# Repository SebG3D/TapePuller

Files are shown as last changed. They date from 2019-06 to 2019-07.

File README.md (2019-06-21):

# TapePuller
tape puller/remover for 0816 automatic feeder which stays within the width of the feeder itself.
Now you will be able to remove on single feeder from your feederbank.

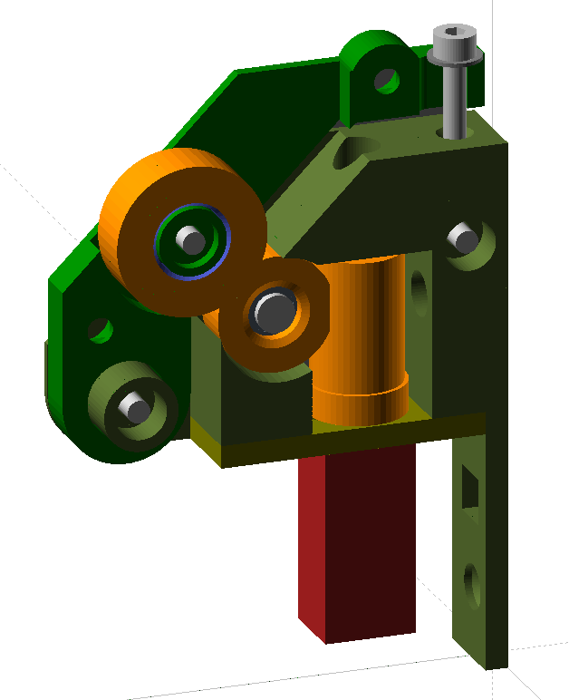
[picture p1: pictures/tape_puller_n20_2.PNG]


Work in progress.
See [wiki](https://github.com/SebG3D/TapePuller/wiki) for details

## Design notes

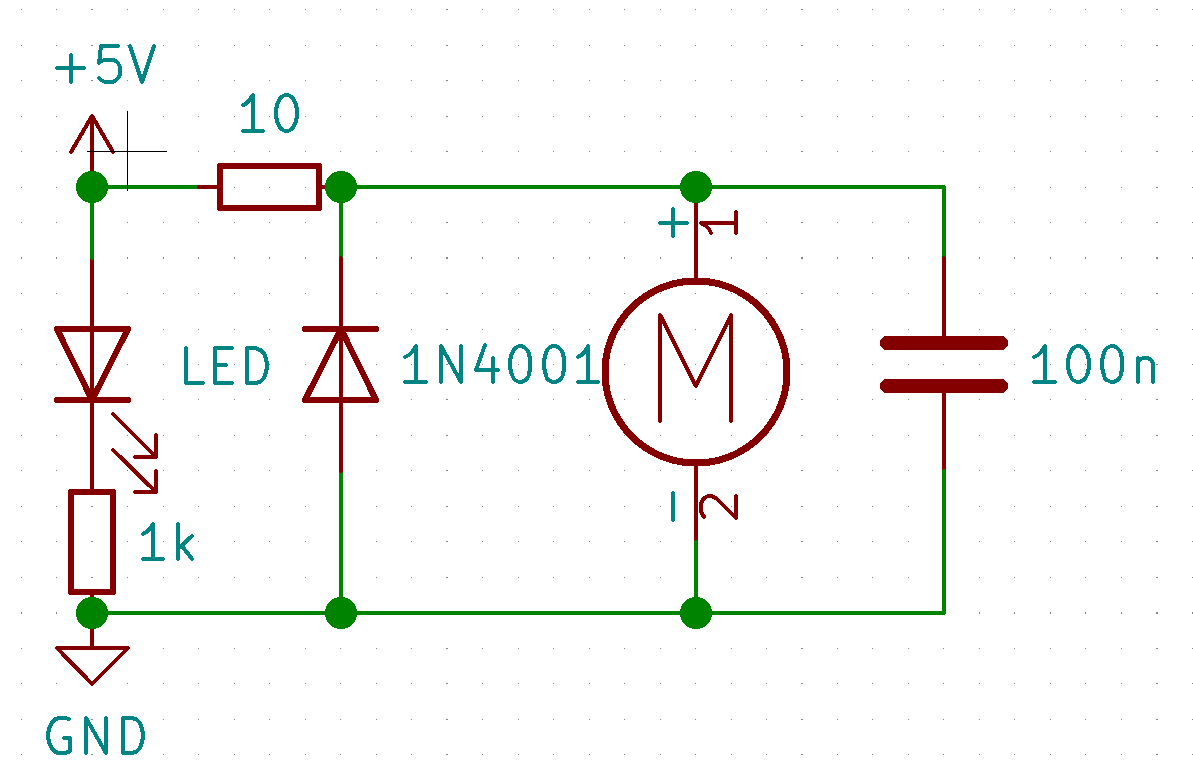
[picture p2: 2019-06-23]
docs/servo/servo_schematic/servo_Schematic.PNG

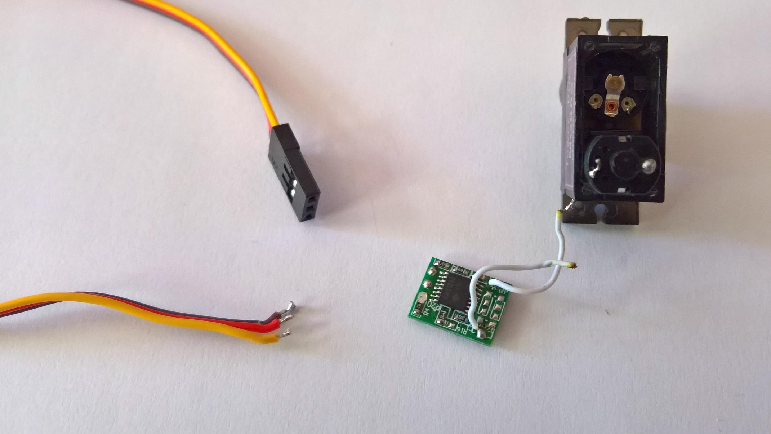
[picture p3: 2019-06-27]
docs/servo/servo_mod/servo_mod_3.jpg

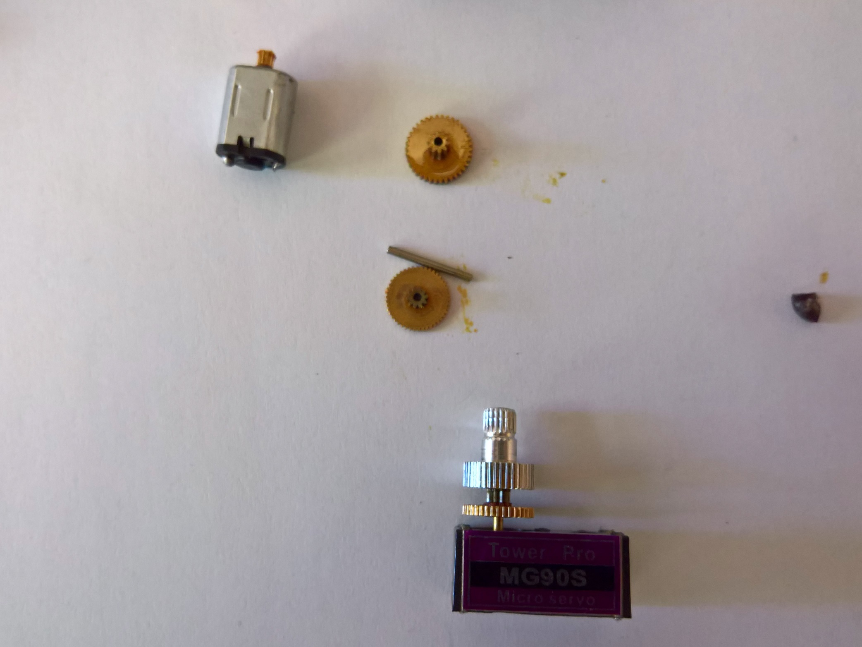
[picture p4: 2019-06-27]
docs/servo/servo_mod/servo_mod_9.jpg

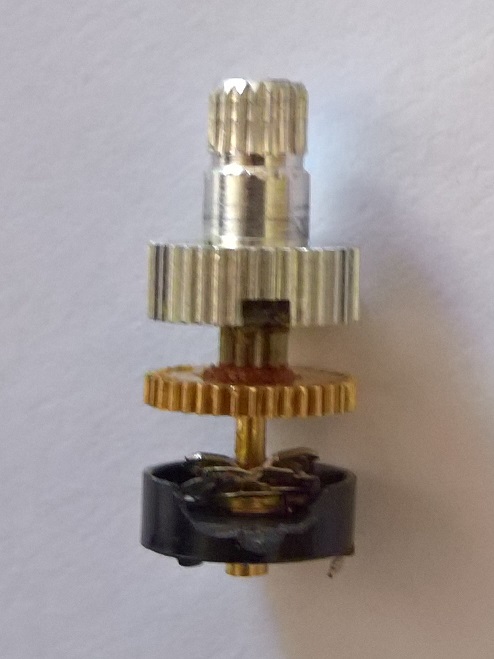
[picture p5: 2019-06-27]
docs/servo/servo_mod/servo_mod_8.jpg

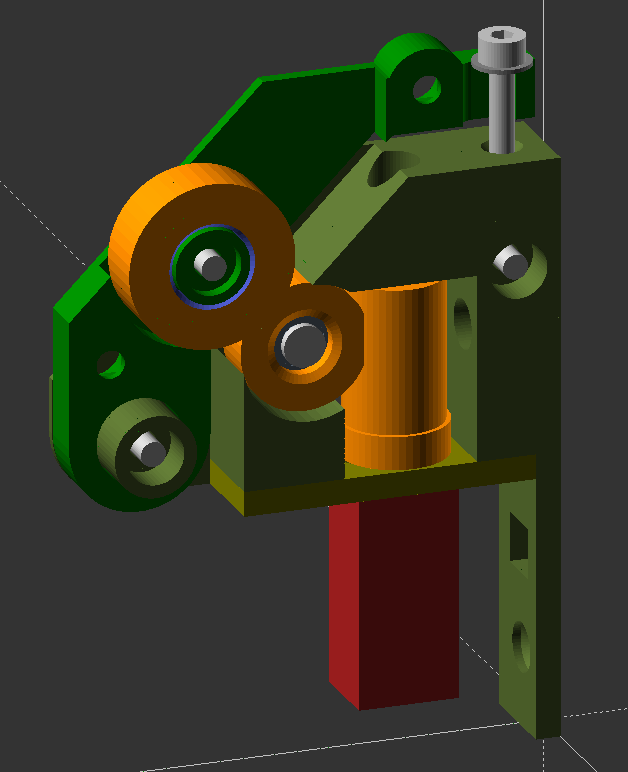
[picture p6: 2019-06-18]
pictures/tape_puller_n20_wo_lid.PNG

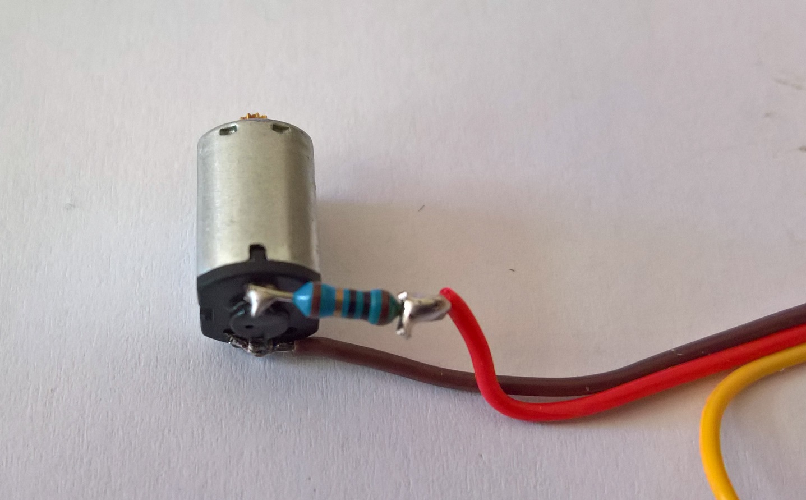
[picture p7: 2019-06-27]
docs/servo/servo_mod/servo_mod_13.jpg

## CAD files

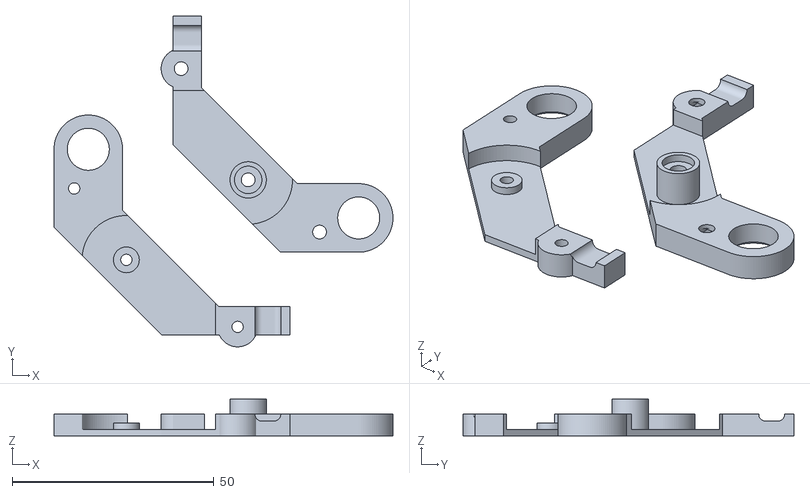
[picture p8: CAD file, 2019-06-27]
STLs/lever_mg90_post.stl
84.0 x 82.0 x 9.12

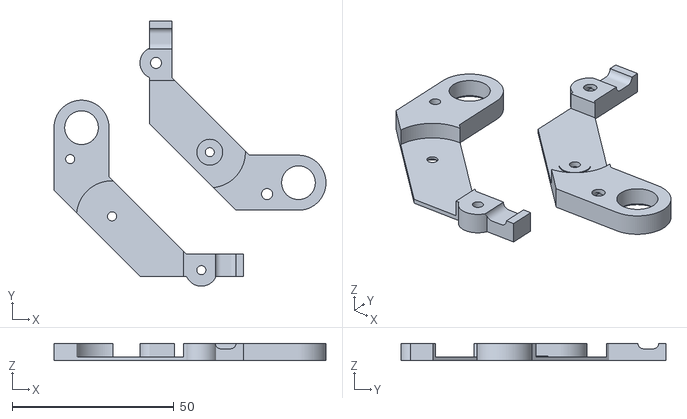
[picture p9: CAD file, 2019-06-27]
STLs/lever_mg90_pin.stl
84.0 x 82.0 x 5.38

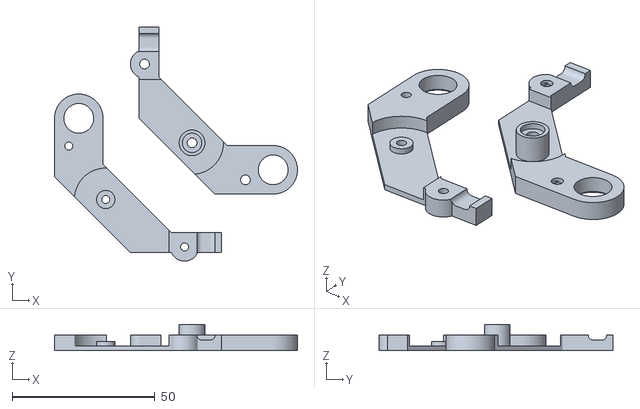
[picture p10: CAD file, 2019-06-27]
STLs/lever_sg90_post.stl
85.0 x 82.0 x 9.12

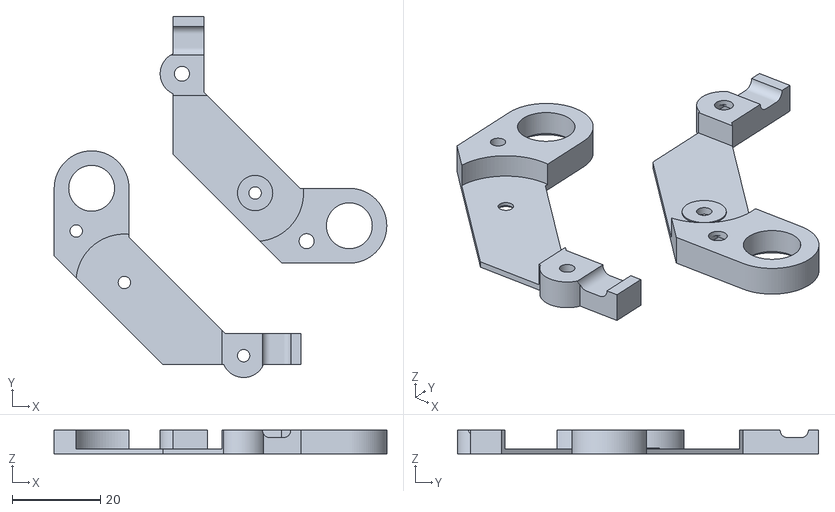
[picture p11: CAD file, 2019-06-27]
STLs/lever_n20_pin.stl
75.5 x 82.0 x 5.38

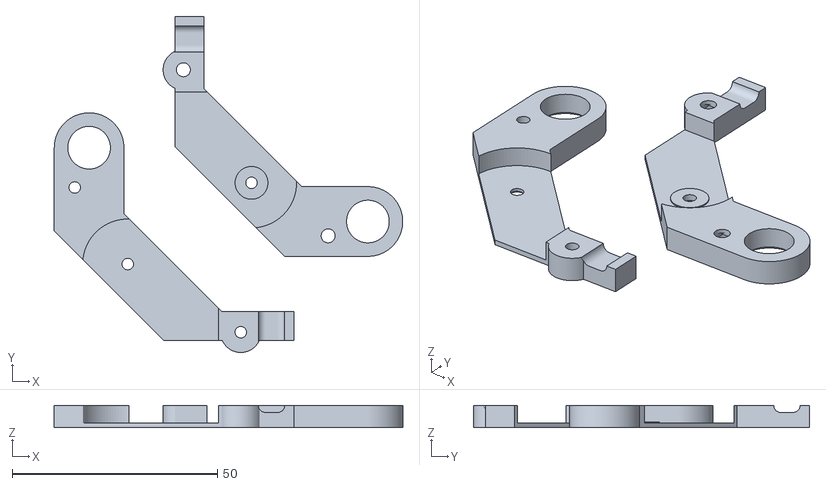
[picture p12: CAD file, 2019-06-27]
STLs/lever_sg90_pin.stl
85.0 x 82.0 x 5.38

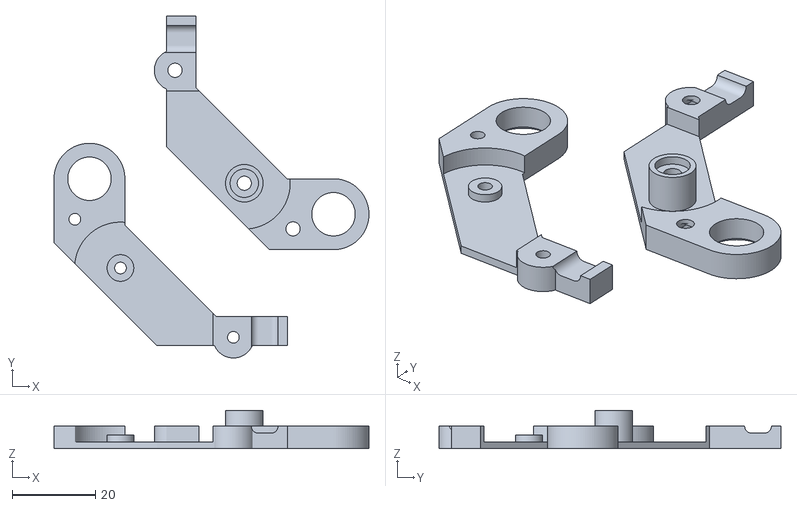
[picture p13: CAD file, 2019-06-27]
STLs/lever_n20_post.stl
75.5 x 82.0 x 9.12

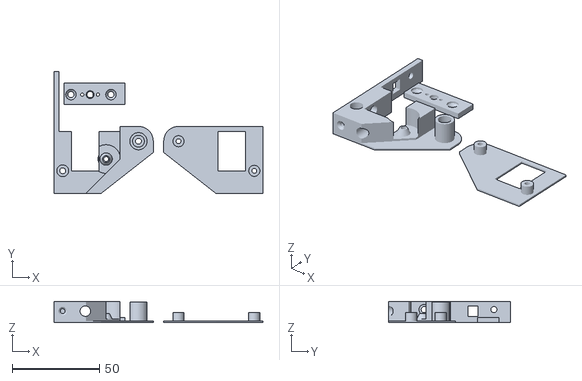
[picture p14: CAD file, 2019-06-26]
STLs/case_N20_ballbearing.stl
120.0 x 70.0 x 12.2

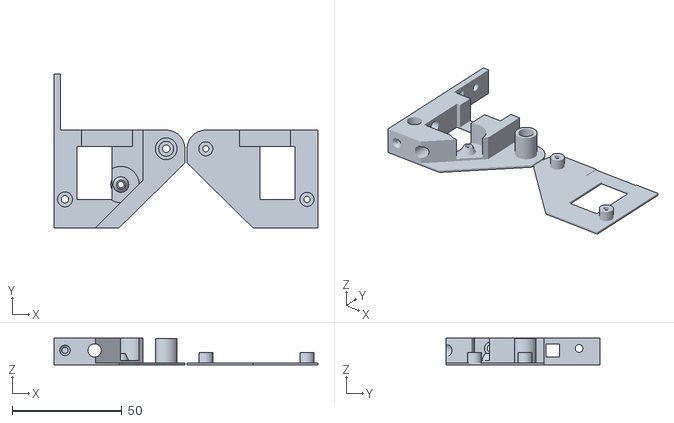
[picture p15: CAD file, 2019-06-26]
STLs/case_mg90_ballbearing.stl
120.0 x 70.0 x 12.2

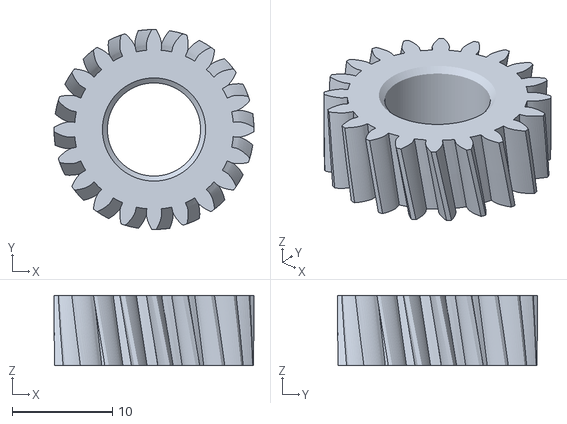
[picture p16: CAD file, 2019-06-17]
STLs/pinnion_2_post.stl
20.0 x 20.0 x 7.00

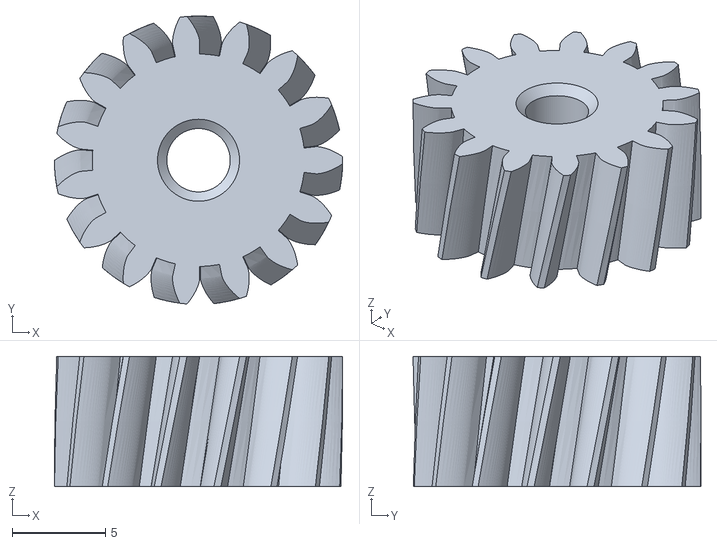
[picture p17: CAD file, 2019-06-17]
STLs/pinnion_1_pin.stl
15.5 x 15.5 x 7.00

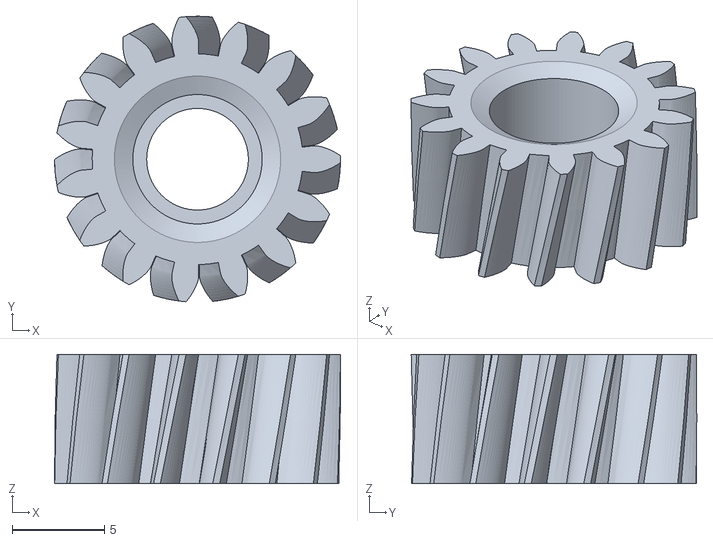
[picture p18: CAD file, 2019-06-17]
STLs/pinnion_1_ballbearing.stl
15.5 x 15.5 x 7.00

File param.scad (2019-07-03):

//-----------------------------------------------------------------------
//                  FEEDER PARAM
//-----------------------------------------------------------------------
//Feeder_Width = 13.5; //[13.5:8mm tape, 16:12mm tape, 20:16mm tape, 28:24mm tape]
feeder_width_list = [13.5,16,20,28];			//list of feeder width for different SMD tape width
Feeder_Width = feeder_width_list[SMD_Tape_Width];
feeder_mount_y_list = [7.55,9.55,11.55,15.55];		//list of y positions for feeder width
feeder_mount_y = feeder_mount_y_list[SMD_Tape_Width];


//-----------------------------------------------------------------------
//                  3D PRINTING PARAM
//-----------------------------------------------------------------------
M3_drill_hole_d = 3D_Printing_M3_tap/1000;  //diameter to directly screw M3 screws in
M3_loose_hole_d = 3D_Printing_M3_through/1000;  //diameter for thouhole
head_912_loose_d = 3D_Printing_M3_head/1000;  //head of a 912 screw helps for worm gear alighnment

//param for gear_mount = 1
gears_pinion_mount_screw = 3D_Printing_Mount_head/1000; //used for geartype==1 gear runs on screw head M3
//param for gear_mount = 2
pin_d_loose = 3D_Printing_Pin_loose/1000;              //hole diameter for loose pin
pin_d_fixed = 3D_Printing_Pin_pressfit/1000;             //hole diameter for press fit
gears_pinion_mount_shim = Shim_Thickness/1000;  //thickness of shim
//param for gear_mount = 3
gears_pinion_mount_683 = 3D_Printing_683_pressfit/1000;   //hole for bearing press fit
gears_pinion_mount_623 = 10.0;   //hole for bearing press fit
//param for gear_mount = 4
gears_pinion_mount_post_id = 9;     //needs to fit in od
gears_pinion_mount_post_od = 3D_Printing_Post_loose/1000;   //needs to fit id

//screw post param for case
//top has cylinder with scew in hole
//bottom has through hole and countersunk scew
case_post_top_od = M3_drill_hole_d + 8*3dp_ew;                   //top outer diameter
case_post_bot_id = head_912_loose_d+0.3;                 //bottom inner diameter needs to fit screw head
case_post_bot_od = case_post_bot_id+8*3dp_ew;  //bottom outer diameter
case_post_bot_id2 = case_post_top_od+0.4; //bottom inner diameter 2 needs to fit top outer diameter


pi = 3.14159;
//-----------------------------------------------------------------------
//                  GEARS PARAM
//-----------------------------------------------------------------------
//param gears, no need to change anything here
RPM_300 =  [20,10,0.9,15,20,2];
RPM_200 =  [20,17,1.0,14,20,3];
RPM_150 =  [20,22,1.0,13,20,4];
RPM_List = [RPM_300,RPM_200,RPM_150];
RPM_Values = RPM_List[N20_RPM];

gears_pressure_angle = RPM_Values[0];              //pressure angel for gears
gears_lead_angle = RPM_Values[1];                  //lead angle for gears
gears_module = RPM_Values[2];                     //module for gearset
gears_pinion1_teeth = RPM_Values[3];                //number of theeth for pinio gears
gears_pinion2_teeth = RPM_Values[4];                //number of theeth for pinio gears
gears_pinion_with = round_lh(Feeder_Width-6.5);                  //with of pinion gears
gears_worm_threads = RPM_Values[5];                 //number of threads on worm gear

//gears_pressure_angle = 20;              //pressure angel for gears
//gears_lead_angle = 10;                  //lead angle for gears
//gears_module = 0.9;                     //module for gearset
//gears_pinion1_teeth = 15;                //number of theeth for pinio gears
//gears_pinion2_teeth = 20;                //number of theeth for pinio gears
//gears_pinion_with = round_lh(Feeder_Width-6.5);                  //with of pinion gears
//gears_worm_threads = 2;                 //number of threads on worm gear
gears_worm_height = round_lh(22);                 //height of worm gear
gears_pinion_mount_683_through = 5.5;   //through hole diameter for 683
gears_pinion_mount_623_through = 8;   //through hole diameter for 623
//some calculated values
c = gears_module / 6;					// Kopfspiel
gears_worm_r = gears_module*gears_worm_threads/(2*sin(gears_lead_angle));		// Teilzylinder-Radius Schnecke
gears_pinion1_r = gears_module*gears_pinion1_teeth/2;									// Teilkegelradius Stirnrad
gears_pinion2_r = gears_module*gears_pinion2_teeth/2;
gears_pinion1_df = 2*gears_pinion1_r - 2 * (gears_module + c);//inner diameter/start of teeth
gears_pinion2_df = 2*gears_pinion2_r - 2 * (gears_module + c);//inner diameter/start of teeth
gears_worm_rf = gears_worm_r - gears_module - c;						// Fußzylinder-Radius
//gamma = -90*gears_pinion_with*sin(gears_lead_angle)/(pi*gears_pinion_r);			// Rotationswinkel Stirnrad
gears_tooth_dist = gears_module*pi/cos(gears_lead_angle);				// gears_tooth_dist im Transversalschnitt
gears_pinion1_ad = (gears_module <1)? gears_pinion1_r*2 + gears_module * 2.2 : gears_pinion1_r*2 + gears_module * 2;				// Kopfkreisdurchmesser nach DIN 58400 bzw. DIN 867
gears_pinion2_ad = (gears_module <1)? gears_pinion2_r*2 + gears_module * 2.2 : gears_pinion2_r*2 + gears_module * 2;
gears_worm_da = gears_worm_r*2.3;

//-----------------------------------------------------------------------
//                  CASE
//-----------------------------------------------------------------------
case_h = 70; //hight of tapepuller case
case_w = round_lh(Feeder_Width - 3dp_lh);
case_walls=3;                           //wall thickness for test assemblys
case_walls_z = 4*3dp_lh;		//wall thickness in Z
case_tape_channel = 2;                  //with of tape channel
case_offset_n20 = 20;			//offset form worm x to tape channel if n20 motor is used

//Feeder_Width = 13.5; //[13.5:8mm tape, 16:12mm tape, 20:16mm tape, 28:24mm tape]
//feeder_width_list = [13.5,16,20,28];			//list of feeder width for different SMD tape width
//Feeder_Width = feeder_width_list[SMD_Tape_Width];
//feeder_mount_y_list = [7.55,9.55,11.55,15.55];		//list of y positions for feeder width
//feeder_mount_y = feeder_mount_y_list[SMD_Tape_Width];

//pramam for positioning
gear1z = case_h-case_walls-gears_pinion1_r-6-4;
//calc gear2 z position with 45°
gear2z = gear1z + (gears_pinion1_r+gears_pinion2_r)/sqrt(2);
wormx = (Motor_Type == 2)? 18 : (servo_mount_l/2-servo_shaft_dist+case_walls+0.5+4);
//wormx = servo_mount_l/2-servo_shaft_dist+case_walls+0.5+4;
gear1x = wormx+gears_worm_r+gears_pinion1_r;
gear2x = gear1x+sqrt(pow(gears_pinion1_r+gears_pinion2_r,2)-pow(gear1z-gear2z ,2));
//added -3,5 for 912 screwhead
wormz = case_h-gears_worm_height-case_walls-0.5-3.5-6;

// param for case lever
case_lever_w = case_w-2*case_walls_z-2*3dp_lh;   //with of lever
case_lever_t1 = 7;                                        //thickness above case
case_lever_t2 = 17;                                       //thickness behind case
rotate_x = (Motor_Type == 2)? (wormx + case_offset_n20 + case_tape_channel+case_lever_t2/2) : (wormx + servo_shaft_dist + servo_mount_l/2 + case_tape_channel+case_lever_t2/2);  //x position of rotation point
rotate_z = (Motor_Type == 2)? (wormz-case_walls+case_lever_t2/2-0.5) : (wormz-servo_arm_dist-servo_mount_dist+case_lever_t2/2);  //z position of rotation point

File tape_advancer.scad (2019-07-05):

/* [Feeder Settings] */

//select the motor to drive the worm gear
Motor_Type = 2; //[0:SG90, 1:MG90, 2:N20]

//select N20 rpm
N20_RPM = 0; //[0:300 rpm, 1:123, 2:456]

//select SMD tape width
SMD_Tape_Width = 0; //[0:8mm tape, 1:12mm tape, 2:16mm tape, 3:24mm tape]

/* [Gear Settings] */

//worm gear mount type
Worm_Mount = 1; //[0:screw head, 1:bearing 683]

//fixed pinion mount type
Pinion_1_Mount = 3; //[1:screw head, 2:pin, 3:bearing 683]

//lever pinion mount type
Pinion_2_Mount = 4; //[2:pin, 4:post]

/* [3D Printing Settings] */

//assemble buildplate or show assembly
Prepare_For_3D_Printing = false;

//create a part to test your settings --- not jet implemented
3D_Printing_Test_Part = false;

//select parts to be created
Part = 0; //[0:worm, 1:pinnion 1, 2:pinnion 2, 3:case, 4:lever]

//layerheight you want to use, fractions of this setting can be used as well
3D_Printing_Layerheight = 0.25; //[0.25:0.25, 0.2:0.2]

//extrusionwith in µm, depends on your nozzle diameter and slicer settings
3D_Printing_Extrusionwidth = 450;

/* [Mechanical Settings] */

//screw type to use to mount to feeder case
Feeder_Mount_Screw = 1; //[0:countersunk, 1:flat head]

//M3 throughhole diameter in µm
3D_Printing_M3_through = 3400;

//M3 tap diameter in µm
3D_Printing_M3_tap = 2800;

//M3 head diameter in µm
3D_Printing_M3_head = 6000;

//GearMount:Screw head diameter, needs to be a tight fit in µm
3D_Printing_Mount_head = 5700;

//GearMount:Pin loose diameter in µm
3D_Printing_Pin_loose = 3400;

//GearMount:Pin pressfit diameter in µm
3D_Printing_Pin_pressfit = 2800;

//GearMount:Ballbearing 683 pressfit diameter in µm
3D_Printing_683_pressfit = 7000;

//GearMount:Post outer diameter, needs to freely turn on 9 mm Post, in µm
3D_Printing_Post_loose = 9300;

//thickness of used M3 shims, 0.5 mm is standard, in µm
Shim_Thickness = 500;

/* [Debug/View] */

//hide hardware/vitamins
Hide_Hardware = false;

//hide lid for more insight
Hide_Lid = false;

//hide motor (servo or N20)
Hide_Motor = false;

//enable cutting assembly
Cut = false;

//cut in x direction
CUT_X = 0; //[0:100]

//cut in y direction
CUT_Y = 0; //[0:100]

//cut height in z direction
CUT_Z = 0; //[0:100]

/* [Hidden] */

//shorten some param for userinterface
3dp_lh = 3D_Printing_Layerheight;
3dp_ew = 3D_Printing_Extrusionwidth/1000;

//use/include librarys
include <libs/hardware.scad>
use <libs/nutsnbolts/cyl_head_bolt.scad>
include <libs/N20.scad>
servo_type = Motor_Type;
include <libs/servo.scad>
include <libs/gears.scad>
include <param.scad>

//***********************************************************************
//                  SMD tape specification
//***********************************************************************
//param order: [B1,D,E,F,K,P0,P1,P2,R,T,W];
//naming after vishay spec
Tape_8mm =  [4.55,1.5,1.75,3.5,2.5,4,2,2,25,0.4,8];
Tape_12mm = [1,2,3,4,5,6,7,8,9,10,11];
Tape_16mm = [1,2,3,4,5,6,7,8,9,10,11];
SMD_tapes = [Tape_8mm,Tape_12mm,Tape_16mm];
Tape = SMD_tapes[SMD_Tape_Width];
B1 = 0;
D = 1;
E = 2;
F = 3;
K = 4;
P0 = 5;
P1 = 6;
P2 = 7;
R = 8;
T = 9;
W = 10;

//case param
case_height = 110;
case_length = 120;
case_width = 20;
case_tape_dist = 1;

difference(){
    partgenerator();
    if (!Prepare_For_3D_Printing){
        if(Cut&&(CUT_X!=0))
            translate ([case_length*CUT_X/100-case_length,-1,-1])cube([case_length,case_width+2,case_height+2],center=false);
        if(Cut&&(CUT_Y!=0))
            translate ([-1,case_width-case_width*CUT_Y/100,-1])cube([case_length+2,case_width,case_height+2],center=false);
        if(Cut&&(CUT_Z!=0))
            translate ([-1,-1,case_height-case_height*CUT_Z/100])cube([case_length+2,case_width+2,case_height],center=false);
    }
}

module partgenerator(){
    //pepare for 3dprinting?
	if (Prepare_For_3D_Printing) {
        //higher resolution for finer details
        $fn = 20;
        // create gears
        translate([60,0,0])bevel_gear(1);
        bevel_gear(2);
        //case
        translate([-40,50,case_width])rotate([-90,0,0])case_bottom(case_height,case_length,case_width,case_tape_dist);
        translate([-40,280,0])rotate([90,0,0])case_top(case_height,case_length,case_width,case_tape_dist);
	}
    //show assembly
	else { 
       // reduce resolution for faster rendering
       $fn = 80;
        case_bottom(case_height,case_length,case_width,case_tape_dist);
        if(!Hide_Lid)case_top(case_height,case_length,case_width,case_tape_dist);
        //bevel_gear(1);
//        translate([60,7-Tape[E]+0.5,case_height-4-76.4/2])
//            rotate([90,0,0])
//                bevel_gear(2);
//        translate([60,7-Tape[E]+0.5,case_height-4-76.4/2])
//            rotate([0,0,0])
//                bevel_gear(1);
    //param copie from gears
    modul=1.2;
    zahnzahl_rad=40;
    zahnzahl_ritzel=11;
    achsenwinkel=90;
    zahnbreite=6;
    bohrung_rad = 4.2;
    bohrung_ritzel=3.2;
    eingriffswinkel = 20;
    schraegungswinkel=10;
    zusammen_gebaut=false;
    spiel = 0.05;	// Spiel zwischen Zähnen
    
    //calc stuff
    r_rad = modul*zahnzahl_rad/2;							// Teilkegelradius des Rads
	delta_rad = atan(sin(achsenwinkel)/(zahnzahl_ritzel/zahnzahl_rad+cos(achsenwinkel)));	// Kegelwinkel des Rads
	delta_ritzel = atan(sin(achsenwinkel)/(zahnzahl_rad/zahnzahl_ritzel+cos(achsenwinkel)));// Kegelwingel des Ritzels
	rg = r_rad/sin(delta_rad);								// Radius der Großkugel
	c = modul / 6;											// Kopfspiel
	df_ritzel = pi*rg*delta_ritzel/90 - 2 * (modul + c);	// Fußkegeldurchmesser auf der Großkugel 
	rf_ritzel = df_ritzel / 2;								// Fußkegelradius auf der Großkugel
	delta_f_ritzel = rf_ritzel/(pi*rg) * 180;				// Kopfkegelwinkel
	rkf_ritzel = rg*sin(delta_f_ritzel);					// Radius des Kegelfußes
	hoehe_f_ritzel = rg*cos(delta_f_ritzel);				// Höhe des Kegels vom Fußkegel
 
	df_rad = pi*rg*delta_rad/90 - 2 * (modul + c);			// Fußkegeldurchmesser auf der Großkugel 
	rf_rad = df_rad / 2;									// Fußkegelradius auf der Großkugel
	delta_f_rad = rf_rad/(pi*rg) * 180;						// Kopfkegelwinkel
	rkf_rad = rg*sin(delta_f_rad);							// Radius des Kegelfußes
	hoehe_f_rad = rg*cos(delta_f_rad);						// Höhe des Kegels vom Fußkegel
	
	drehen = istgerade(zahnzahl_ritzel);
    
    translate([60,case_width-case_tape_dist-Tape[E]+0.5,case_height-4-76.4/2])
        rotate([90,0,0])
            union(){
                // Rad
                rotate([0,0,180*(1-spiel)/zahnzahl_rad*drehen])
                    bevel_gear(2);
                // Ritzel
                    translate([-hoehe_f_ritzel*cos(90-achsenwinkel),0,hoehe_f_rad-hoehe_f_ritzel*sin(90-achsenwinkel)+4])
                        rotate([0,achsenwinkel,0])
                            {bevel_gear(1);if(!Hide_Motor)translate([0,0,-2])rotate([0,0,90])N20();}
                }
    }
}

module case_bottom(h,l,w,tape){
    //calc top and bottom separation position
    top_bot_sep = tape+Tape[E]+Tape[F]-Tape[B1]/2+0.025;
    difference(){
        case(h,l,w,tape);
        translate([-1,-top_bot_sep,-1])cube([l+2,w,h+2],center=false);
    }
    //wheel mount
    wheel_y = w-tape-Tape[E]+0.5;
    offset_bearing = 2;
    mount_height = w - wheel_y + offset_bearing;
    case_gear_mounts(60,w,h-4-76.4/2,90,0,0,mount_height);
}

module case_top(h,l,w,tape){
    //calc top and bottom separation position
    top_bot_sep = tape+Tape[E]+Tape[F]-Tape[B1]/2+0.025;
    difference(){
        case(h,l,w,tape);
        translate([-1,w-top_bot_sep,-1])cube([l+2,w,h+2],center=false);
    }
}
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

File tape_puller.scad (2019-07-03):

/* [Feeder Settings] */

//select the motor to drive the worm gear
Motor_Type = 2; //[0:SG90, 1:MG90, 2:N20]

//select N20 rpm
N20_RPM = 0; //[0:300 rpm, 1:200 rpm, 2:150 rpm]

//select SMD tape width
SMD_Tape_Width = 0; //[0:8mm tape, 1:12mm tape, 2:16mm tape, 3:24mm tape]

/* [Gear Settings] */

//worm gear mount type
Worm_Mount = 1; //[0:screw head, 1:bearing 683]

//fixed pinion mount type
Pinion_1_Mount = 3; //[1:screw head, 2:pin, 3:bearing 683]

//lever pinion mount type
Pinion_2_Mount = 4; //[2:pin, 4:post]

/* [3D Printing Settings] */

//assemble buildplate or show assembly
Prepare_For_3D_Printing = false;

//create a part to test your settings --- not jet implemented
3D_Printing_Test_Part = false;

//select parts to be created
Part = 0; //[0:worm, 1:pinnion 1, 2:pinnion 2, 3:case, 4:lever]

//layerheight you want to use, fractions of this setting can be used as well
3D_Printing_Layerheight = 0.25; //[0.25:0.25, 0.2:0.2]

//extrusionwith in µm, depends on your nozzle diameter and slicer settings
3D_Printing_Extrusionwidth = 450;

/* [Mechanical Settings] */

//screw type to use to mount to feeder case
Feeder_Mount_Screw = 1; //[0:countersunk, 1:flat head]

//M3 throughhole diameter in µm
3D_Printing_M3_through = 3400;

//M3 tap diameter in µm
3D_Printing_M3_tap = 2800;

//M3 head diameter in µm
3D_Printing_M3_head = 6000;

//GearMount:Screw head diameter, needs to be a tight fit in µm
3D_Printing_Mount_head = 5700;

//GearMount:Pin loose diameter in µm
3D_Printing_Pin_loose = 3400;

//GearMount:Pin pressfit diameter in µm
3D_Printing_Pin_pressfit = 2800;

//GearMount:Ballbearing 683 pressfit diameter in µm
3D_Printing_683_pressfit = 7000;

//GearMount:Post outer diameter, needs to freely turn on 9 mm Post, in µm
3D_Printing_Post_loose = 9300;

//thickness of used M3 shims, 0.5 mm is standard, in µm
Shim_Thickness = 500;

/* [Debug/View] */

//hide hardware/vitamins
Hide_Hardware = false;

//hide lid for more insight
Hide_Lid = false;

//hide motor (servo or N20)
Hide_Motor = false;

//enable cutting assembly
Cut = false;

//cut in x direction
CUT_X = 0; //[0:100]

//cut in y direction
CUT_Y = 0; //[0:100]

//cut height in z direction
CUT_Z = 0; //[0:100]

/* [Hidden] */

//shorten some param for userinterface
3dp_lh = 3D_Printing_Layerheight;
3dp_ew = 3D_Printing_Extrusionwidth/1000;

echo("TODO");
echo("reduce screw variaty");
echo("------Releas Version-------------");
echo("6 ballbearing gear 2");
echo("1 chamfer on self tap screws");
echo("3 Testteil einbauen");
echo("5 case_mounts add inside and outside chamfer to strengthen lid post");
echo("5 print BOM");
echo("7 screws for servo and N20 mounting");
echo("10 calc cost");

//use/include librarys
include <libs/hardware.scad>
use <libs/nutsnbolts/cyl_head_bolt.scad>
include <libs/N20.scad>
servo_type = Motor_Type;
include <libs/servo.scad>
include <libs/gears.scad>
include <param.scad>

difference(){
    partgenerator();
    if (!Prepare_For_3D_Printing){
        if(Cut&&(CUT_X!=0))
            translate ([100*CUT_X/100-100,-25,0])cube([100,50,100],center=false);
        if(Cut&&(CUT_Y!=0))
            translate ([-5,case_w/2-case_w*CUT_Y/100,-5])cube([100,50,100],center=false);
        if(Cut&&(CUT_Z!=0))
            translate ([0,-25,80-80*CUT_Z/100])cube([100,50,100],center=false);
    }
}


module partgenerator(){
    //pepare for 3dprinting?
	if (Prepare_For_3D_Printing) {
        //higher resolution for finer details
        $fn = 96;
        //all parts - removed caused scad to crash
//        if (Part==0){
//            // create gears
//            translate([gears_worm_r,0,0])gear(5+Motor_Type,Worm_Mount);
//            translate([-2*gears_pinion1_r,0,gears_pinion_with])rotate([180,0,0])gear(Pinion_2_Mount,Worm_Mount);
//            translate([-(gears_pinion2_r+gears_worm_r)/2,-2.5*gears_pinion2_r,gears_pinion_with])rotate([180,0,0])gear(Pinion_1_Mount,Worm_Mount,true);
//            //case + lever
//            translate([gears_worm_r*3,0,case_w/2])rotate([90,0,0])case(1);
//            translate([2*case_h,0,case_w/2])rotate([90,180,0])case(2);
//            if (Motor_Type == 2)
//                translate([gears_worm_r*8,-case_w,0])
//                    rotate([180,0,0])
//                        translate([-wormx,0,-wormz+0.5])case(3);
//            translate([-(gears_pinion2_r+gears_worm_r)/2+40,-2.5*gears_pinion2_r+20,case_lever_w/2])rotate([90,0,-90])case_lever(1);
//            translate([-(gears_pinion2_r+gears_worm_r)/2-10,-2.5*gears_pinion2_r+20,case_lever_w/2])rotate([-90,0,180])case_lever(2);
//        }
        //worm
        if (Part==0){
            translate([0,0,0])gear(5+Motor_Type,Worm_Mount);
        }
        //pinnion 1
        if (Part==1){
            translate([0,0,gears_pinion_with])rotate([180,0,0])gear(Pinion_1_Mount,Worm_Mount,true);
        }
        //pinnion 2
        if (Part==2){
            translate([0,0,gears_pinion_with])rotate([180,0,0])gear(Pinion_2_Mount,Worm_Mount);
        }
        //case
        if (Part==3){
            translate([-case_h+10,0,case_w/2])rotate([90,0,0])case(1);
            translate([+case_h-10,0,case_w/2])rotate([90,180,0])case(2);
            if (Motor_Type == 2)
                translate([-case_h+10+gears_worm_r*4,-case_w,0])
                    rotate([180,0,0])
                        translate([-wormx,0,-wormz+0.5])case(3);
        }
        //lever
        if (Part==4){
            translate([70,40,case_lever_w/2])rotate([90,0,-90])case_lever(1);
            translate([20,40,case_lever_w/2])rotate([-90,0,180])case_lever(2);
        }
	}
    //show assembly
	else { 
       // reduce resolution for faster rendering
       $fn = 20;
        //wormgear
        translate([wormx,0,wormz])
            rotate([0,0,90])
                gear_dummy(5+Motor_Type,Worm_Mount);
        //gear1
        translate([gear1x,gears_pinion_with/2,gear1z])
            rotate([90,0,0])
                gear_dummy(Pinion_1_Mount,Worm_Mount,true);
        //gear2
        translate([gear2x,-gears_pinion_with/2,gear2z])
            rotate([-90,0,0])
                gear_dummy(Pinion_2_Mount,Worm_Mount,false);
        //case
        if(!Hide_Lid) color("GreenYellow")case(2);
        color("DarkOliveGreen")translate([0,0.01,0])case(1);
        if(Motor_Type == 2) color("Olive")case(3); 
        //case lever
        color("Green")case_lever(1);
        if(!Hide_Lid) color("Green")case_lever(2);
        //servo + screws
        if (((Motor_Type==0)||(Motor_Type==1))&&(!Hide_Motor)){
            translate([wormx,0,wormz-servo_arm_dist])rotate([0,180,180])servo();
            echo("add screws here");
            //if(!Hide_Hardware))
        }
        //N20
        if ((Motor_Type==2)&&(!Hide_Motor)){
            translate([wormx,0,wormz-case_walls])rotate([0,0,0])N20();
            echo("add screws here");
            //if(!Hide_Hardware))
        }
        
        //mounted on screw -> create screws
        if ((Pinion_1_Mount==1)&&(!Hide_Hardware)){
            color("Silver")translate([gear1x,-gears_pinion_with/2+3,gear1z])rotate([-90,0,0])screw("M3x6");
            translate([gear1x,-gears_pinion_with/2-0.5,gear1z])rotate([-90,0,0])hardware_shim(3.2,7,gears_pinion_mount_shim);
        }
        //gear 1 mounted on pin -> creat pin
        if ((Pinion_1_Mount==2)&&(!Hide_Hardware)){
            //add pins
            translate([gear1x,6+0.45,gear1z])rotate([-90,0,0])hardware_pin_din7(3,12,0.45);
            //add shims
            translate([gear1x,-gears_pinion_with/2-gears_pinion_mount_shim,gear1z])rotate([-90,0,0])hardware_shim(3.2,7,gears_pinion_mount_shim);
            translate([gear1x,+gears_pinion_with/2,gear1z])rotate([-90,0,0])hardware_shim(3.2,7,gears_pinion_mount_shim);
        }
        //gear 1 mounted bearing -> create bearing
        if ((Pinion_1_Mount==3)&&(!Hide_Hardware)){
            translate([gear1x,-gears_pinion_with/2+2,gear1z])rotate([-90,0,0])hardware_bearing_683();
            //screws for bearing
            hardware_screw_din7991(gear1x,-gears_pinion_with/2+2+4.5,gear1z,90,0,0,3,8,5);
//            echo("Bearing 683");
//            echo("Din 7991 M3x8 683");
        }
        //gear 2 mounted on pin -> creat pin
        if ((Pinion_2_Mount==2)&&(!Hide_Hardware)){
            //add pin
            translate([gear2x,5+0.45,gear2z])
                rotate([-90,0,0])
                    hardware_pin_din7(3,10,0.45);
            //add shims on both sides
            translate([gear2x,-gears_pinion_with/2-gears_pinion_mount_shim,gear2z])rotate([-90,0,0])hardware_shim(3.2,7,gears_pinion_mount_shim);
            translate([gear2x,+gears_pinion_with/2,gear2z])rotate([-90,0,0])hardware_shim(3.2,7,gears_pinion_mount_shim);
        }
        //gear 2 mounted on post -> creat scew -> screw connects both lever halfs
        if ((Pinion_2_Mount==4)&&(!Hide_Hardware)){
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

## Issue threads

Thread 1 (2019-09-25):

24mm with N20 motor generates overlapping parts

scott-t-wilson, 2019-09-25:
The N20 mount and case overlap on 24mm wide pullers. I worked around by changing line 618 from:

`        translate([0,-case_w/2,0])`

to

`        translate([0,-case_w,0])`

I can submit a pull request, but you may not want the location moved for the other widths.

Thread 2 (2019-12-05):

Tape jamming and burning out SG90 motors

CircuitSetup, 2019-12-05:
One issue I've been having is SG90 motors burning out when tape gets bunched up and jammed. Usually when this happens the tape ends up going around the larger top gear. I'm not sure of the best way to prevent this from happening.

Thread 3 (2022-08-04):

Improvement suggestion - gear tensioning system

noeldum, 2022-08-04:
One of the problem I find is the top screw that act as a tensioner for the gears.
* It is really close to the tape switch lever and has limited range. If left too high it can prevent the tape switch lever from stopping the motor.
* The film goes over it and prevent easy access to it. It is slightly awkward when removing the film. We normally need to remove the film when changing components or if the film jams.

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

May I suggest something like this below?

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

* Relocating the screw at the back will allow easy access to the screw for removal and maintenance. Plus the range of tensioning will not be limited.
* Also we could use a small screw knob for not having to use an allen key.

I would do the change if I knew more about scad but I am more a freecad guy.

Let us know what you guys think of that solution?

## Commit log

2019-06-17 initial upload
    [case_N20_ballbearing.stl, case_N20_screw.stl, case_sg90_ballbearing.stl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]
2019-06-17 added servo param explanation
2019-06-23 added servo schematic
    [servo_schematic.sch]
2019-06-23 sg90 + mg90 fix
    * fixed some values for SG90 param which were not 100% correct
    * added mg90 / checked param for the first time -> needs testing
    * fixed error in servo_param doc for servo lib
2019-06-26 added screw option
    added screw option for flat head screws to mount case to feeder...
    [tape_puller.scad]
2019-06-26 New STLs
    to sum up past improvments
    switched to flat head scew for mounting to feeder
    [case_N20_ballbearing.stl, case_N20_screw.stl, case_mg90_ballbearing.stl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]
2019-06-27 New STLs for lever
    forgot to update these last night
    [lever_mg90_pin.stl, lever_mg90_post.stl, lever_n20_pin.stl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]
2019-06-27 diffrent feeder width should work now
    added diffrent screw positions for different feeder width
    [param.scad, tape_puller.scad]
2019-06-27 fixed hole for cable position
    which is now also dependet on feeder width
    [tape_puller.scad]
2019-06-27 added pics for servo mod
2019-07-03 added option for different N20 rpm
    [param.scad, tape_advancer.scad, tape_puller.scad]
2019-07-05 added encoder dents to advancer wheel
2019-07-05 some work on tape advancer
    [tape_advancer.scad]
